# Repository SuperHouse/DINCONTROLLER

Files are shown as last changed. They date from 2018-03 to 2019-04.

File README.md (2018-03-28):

DIN-Mount ESP32 Controller with I/O Breakout
=============================================
Copyright 2017-2018 SuperHouse Automation Pty Ltd  www.superhouse.tv  

ESP32 controller board designed to fit into the top part of DIN rail
case H8456.

Includes 8 illuminated buttons for input, and an I/O Breakout header
(12-pin IDC) compatible with other I/O Breakout boards from SuperHouse.

More information is available at:

  http://www.superhouse.tv/dinrelay8

INSTALLATION
------------
The design is saved as an EAGLE project. EAGLE PCB design software is
available from www.cadsoftusa.com free for non-commercial use. To use
this project download it and place the directory containing these files
into the "eagle" directory on your computer. Then open EAGLE and
navigate to the project.

DISTRIBUTION
------------
The specific terms of distribution of this project are governed by the
license referenced below.

LICENSE
-------
Licensed under the TAPR Open Hardware License (www.tapr.org/OHL).
The "license" folder within this repository also contains a copy of
this license in plain text format.

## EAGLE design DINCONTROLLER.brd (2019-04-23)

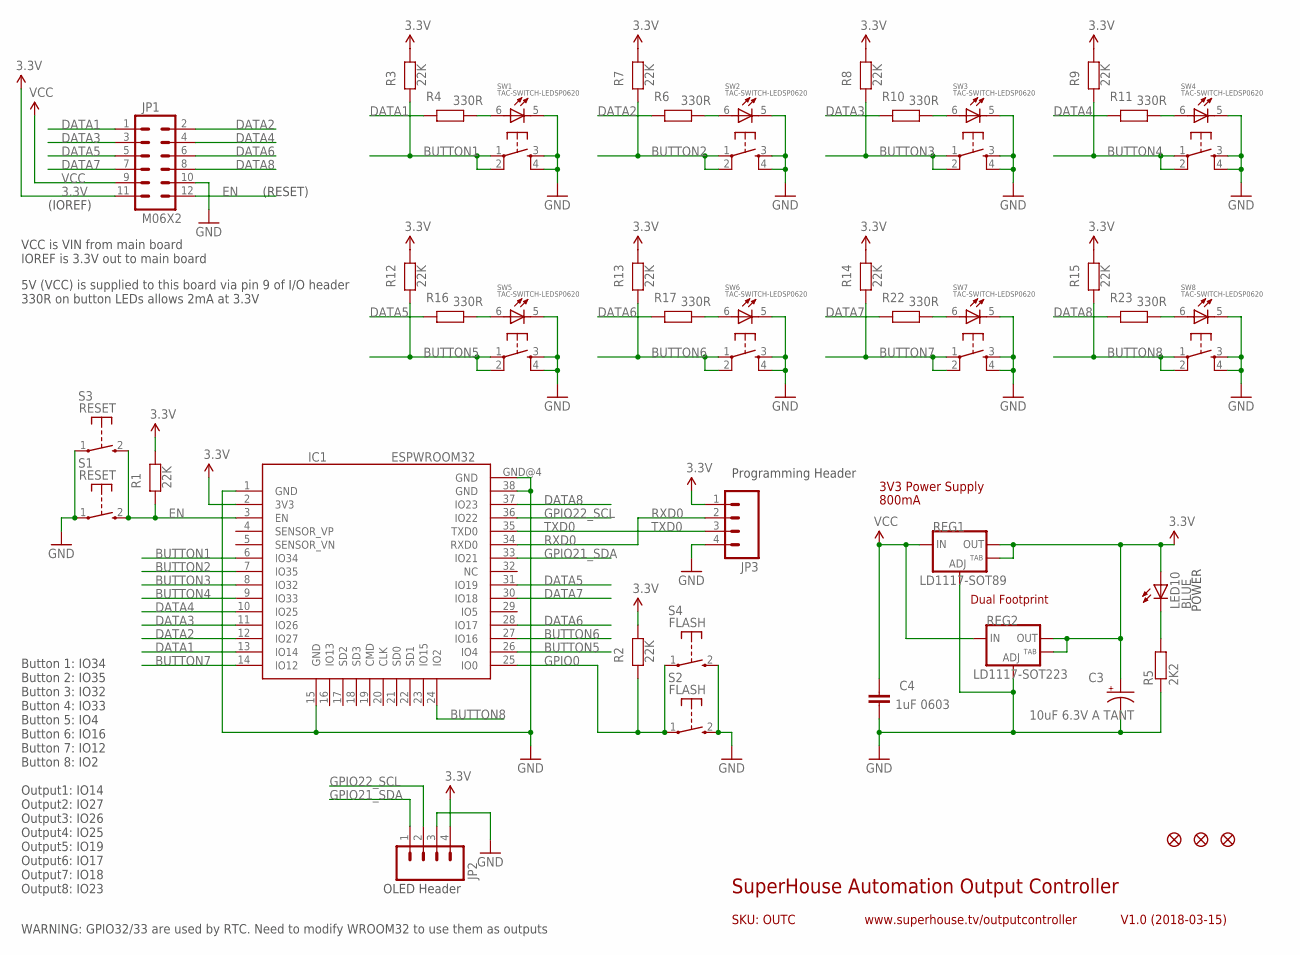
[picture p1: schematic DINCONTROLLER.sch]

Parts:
C3: 10uF 6.3V A TANT; EIA3216
C4: 1uF 0603; 0603
FID1, FID2, FID3: FIDUCIAL1X2.5; FIDUCIAL-1X2.5
IC1: ESPWROOM32
JP1: M06X2; 2X6-SHROUDED
JP2, JP3: M04PTH; 1X04
LED10: BLUE; LED3MM
R1, R2, R3, R7, R8, R9, R12, R13, R14, R15: 22K; 0603@2
R4, R6, R10, R11, R16, R17, R22, R23: 330R; 0603@2
R5: 2K2; 0603
REG1: LD1117-SOT89; SOT89
REG2: LD1117-SOT223; SOT223
S1, S3: RESET; TACTILE_SWITCH_SMD_2PIN_TINY
S2, S4: FLASH; TACTILE_SWITCH_SMD_2PIN_TINY
SW1, SW2, SW3, SW4, SW5, SW6, SW7, SW8: TAC-SWITCH-LEDSP0620; TACTILE-PTH-SP0620

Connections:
3.3V: C3.A (+), IC1.2 (3V3), JP1.11, JP2.4, JP3.1, LED10.A, R1.1, R2.1, R3.1, R7.1, R8.1, R9.1, R12.1, R13.1, R14.1, R15.1, REG1.2 (OUT), REG1.4 (OUT), REG2.2 (OUT), REG2.4 (OUT)
BUTTON1: IC1.6 (IO34), R3.2, SW1.1, SW1.2 (6)
BUTTON2: IC1.7 (IO35), R7.2, SW2.1, SW2.2 (6)
BUTTON3: IC1.8 (IO32), R8.2, SW3.1, SW3.2 (6)
BUTTON4: IC1.9 (IO33), R9.2, SW4.1, SW4.2 (6)
BUTTON5: IC1.26 (IO4), R12.2, SW5.1, SW5.2 (6)
BUTTON6: IC1.27 (IO16), R13.2, SW6.1, SW6.2 (6)
BUTTON7: IC1.14 (IO12), R14.2, SW7.1, SW7.2 (6)
BUTTON8: IC1.24 (IO2), R15.2, SW8.1, SW8.2 (6)
DATA1: IC1.13 (IO14), JP1.1, R4.2
DATA2: IC1.12 (IO27), JP1.2, R6.2
DATA3: IC1.11 (IO26), JP1.3, R10.2
DATA4: IC1.10 (IO25), JP1.4, R11.2
DATA5: IC1.31 (IO19), JP1.5, R16.2
DATA6: IC1.28 (IO17), JP1.6, R17.2
DATA7: IC1.30 (IO18), JP1.7, R22.2
DATA8: IC1.37 (IO23), JP1.8, R23.2
EN: IC1.3 (EN), JP1.12, R1.2, S1.2 (S), S3.2 (S)
GND: C3.C (-), C4.2, IC1.1 (GND), IC1.15 (GND), IC1.38 (GND), IC1.GND@4 (GND), JP1.10, JP2.3, JP3.4, R5.1, REG1.1 (ADJ), REG2.1 (ADJ), S1.1, S2.2 (S), S3.1, S4.2 (S), SW1.3, SW1.4, SW1.5 (C), SW2.3, SW2.4, SW2.5 (C), SW3.3, SW3.4, SW3.5 (C), SW4.3, SW4.4, SW4.5 (C), SW5.3, SW5.4, SW5.5 (C), SW6.3, SW6.4, SW6.5 (C), SW7.3, SW7.4, SW7.5 (C), SW8.3, SW8.4, SW8.5 (C)
GPIO0: IC1.25 (IO0), R2.2, S2.1, S4.1
GPIO21_SDA: IC1.33 (IO21), JP2.1
GPIO22_SCL: IC1.36 (IO22), JP2.2
unnamed: R4.1, SW1.6 (A)
unnamed: R11.1, SW4.6 (A)
unnamed: R6.1, SW2.6 (A)
unnamed: R10.1, SW3.6 (A)
unnamed: LED10.K (C), R5.2
unnamed: R16.1, SW5.6 (A)
unnamed: R17.1, SW6.6 (A)
unnamed: R22.1, SW7.6 (A)
unnamed: R23.1, SW8.6 (A)
RXD0: IC1.34 (RXD0), JP3.2
TXD0: IC1.35 (TXD0), JP3.3
VCC: C4.1, JP1.9, REG1.3 (IN), REG2.3 (IN)

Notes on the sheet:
SKU: OUTC
SuperHouse Automation Output Controller
V1.0 (2018-03-15)
www.superhouse.tv/outputcontroller
Button 1: IO34 Button 2: IO35 Button 3: IO32 Button 4: IO33 Button 5: IO4 Button 6: IO16 Button 7: IO12 Button 8: IO2 Output1: IO14 Output2: IO27 Output3: IO26 Output4: IO25 Output5: IO19 Output6: IO17 Output7: IO18 Output8: IO23
VCC is VIN from main board IOREF is 3.3V out to main board
5V (VCC) is supplied to this board via pin 9 of I/O header 330R on button LEDs allows 2mA at 3.3V
POWER
3V3 Power Supply
Dual Footprint
800mA
(IOREF)
WARNING: GPIO32/33 are used by RTC. Need to modify WROOM32 to use them as outputs
OLED Header
Programming Header
(RESET)

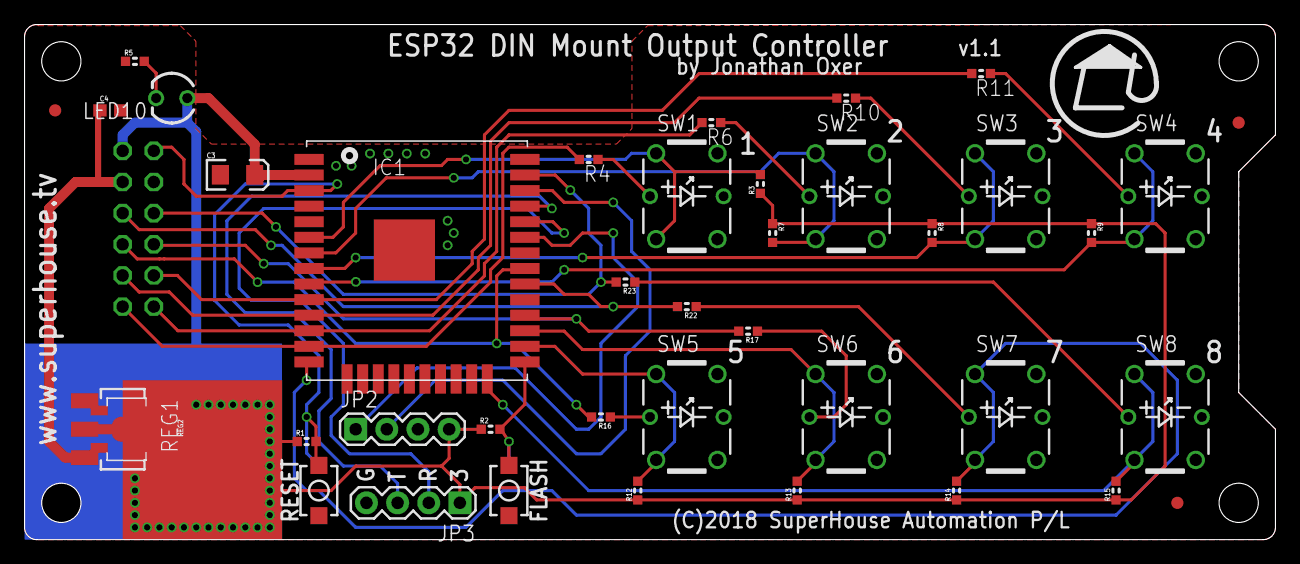
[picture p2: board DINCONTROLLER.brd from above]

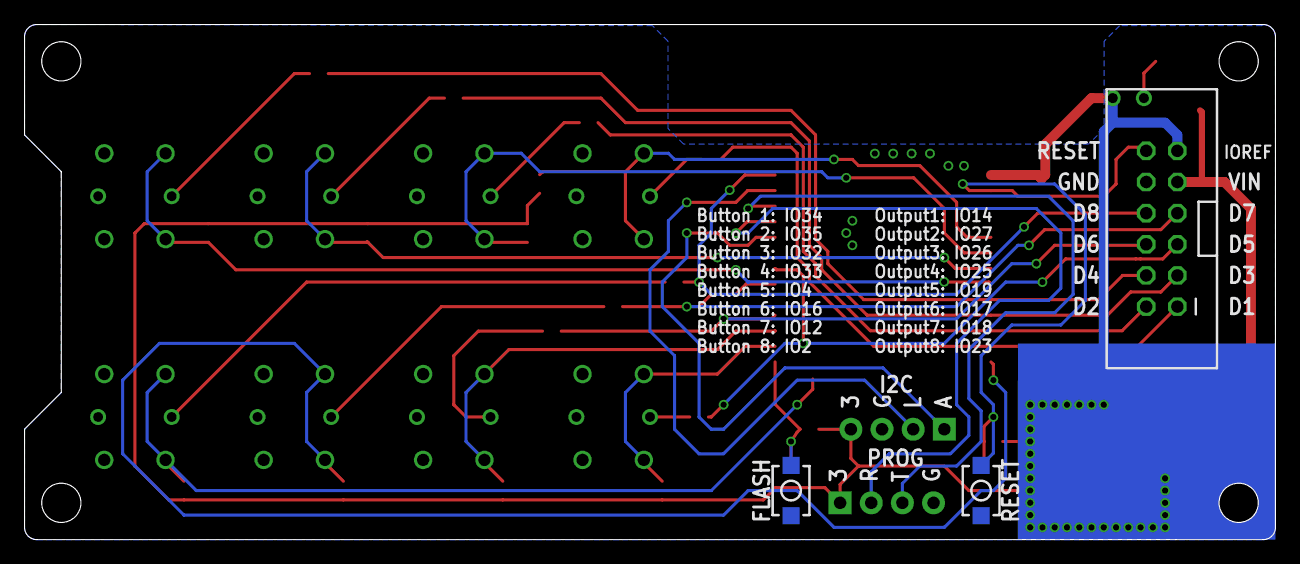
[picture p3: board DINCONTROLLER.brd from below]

Board: 2 copper layers, 102.0 x 42.0 mm, 43 parts (3 on the bottom side), 34 nets.

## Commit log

2018-03-28 Initial project import
    [DINCONTROLLER.brd, DINCONTROLLER.sch]
2018-04-10 Improved designators
    [DINCONTROLLER.brd, DINCONTROLLER.sch]
2018-04-22 Updated notes for v1.0 release
    [DINCONTROLLER.sch]
2018-04-23 Major update: remapped IO pins for v1.1 release
    [DINCONTROLLER.brd, DINCONTROLLER.sch]
2019-04-23 Improved designator visibility
    [DINCONTROLLER.brd]

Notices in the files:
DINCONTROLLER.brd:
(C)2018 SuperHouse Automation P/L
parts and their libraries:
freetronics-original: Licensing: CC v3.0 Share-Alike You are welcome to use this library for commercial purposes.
